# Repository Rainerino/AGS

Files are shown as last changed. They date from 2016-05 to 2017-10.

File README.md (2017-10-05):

## Project name: Air Guitar System(AGS)

Group memeber: 

Carmen Sing

John Kim

Yiyi Yan

Harry Li

Ringo Wong

## Introduction

The Air Guitar System (AGS) is designed to mimic the abilities of an electric guitar but playability of a simple button pushing device.  

Much of the design consideration has been geared towards stimulating accurate sound of electric guitar and creating easy to use interface in order to mitigate a learning curve.  

With these requirements in mind, our team created a fully functional instrument that can be played anytime, anywhere.  Our "guitar" do not require strings, large sound board or further tuning.  Aside from mimicking the ability of a regular guitar to stop music and vary volumes based on strumming patterns, many additional features have been included to improve upon a regular guitar such as one for all strumming distance, virtual button replacing the painful picking experiencec. 

## Motivation

Throughout history a common outlet for creativity is through music.  Research has shown that guitar is gaining traction by fast becoming the most popular instrument played due to its versatility, relatively lower cost (compared to pianos) and the rise of rock and pop music.  Our team aims to bring the freedom of creative expression to everyone while addressing some common complaints.  There have been similar projects in the past, however, our project aims to further improve the instrument by targeting problematic areas such as further reducing the cost of, and improving the portability and ease of composition.  We aim to accomplish two things: to simplify the instrument and to construct an intuitive design.  

## Prerequisities
* [Arduino](https://www.arduino.cc/en/Main/Software)
* [SFE_MMA8452Q library](https://learn.sparkfun.com/tutorials/mma8452q-accelerometer-breakout-hookup-guide/example-code)
* [toneAC library](https://playground.arduino.cc/Code/ToneAC)

## Modules 
Modules | Designation
--- | :---:
1 | Team_Resistor (main)
2 | Components
3 | Sound Calculation

### Components

This module is implemented in Project.header file. The functions of Components module included ultrasonic(), accGyro(), buttons() and pitch(). Each of the functions act as the driver for each sensors. 

### Sound Calculation

This module composes of two functions: playSound(), setPin() and the header file pitch.h, which has the wave defination od different notes to generate a song. The array chords in the Project header is a tester for the function. 

## Code Example

\#include "Project.h"
Project guitar; 
void setup() 
{
  guitar.setPin();
}
void loop() 
{
  guitar.playSound(); 
}

## References

See Final documentation.docx

## Contributors
Carmen Sing: csing00@langara.bc.ca

John Kim:hkim52@langara.bc.ca

Yiyi Yan: yyan10@langara.bc.ca

Harry Li: mli43@langara.bc.ca 

Ringo Wong: rwong22@langara.bc.ca

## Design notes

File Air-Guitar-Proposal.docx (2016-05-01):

Arduino Air Guitar

Description

The goal of this project is to create a guitar using the Arduino MEGA 2560 by replicating the both the sounds and playstyle of an actual guitar; without the strings and fret board. Using ultrasonic sensors, the distance between either hands will be measured to determine the fret and strings (buttons) to play the correct tone. On the other hand, an accelerometer with gyroscope will be used to determine whether the user is strumming or not. With the air guitar, the user will be able to simply strum in the air to play music.

Objectives

1. Create a functional air guitar with the Arduino MEGA 2560
2. Four strings playback as an acoustic guitar (and multiple instruments if time permits (e.g. acoustic/electric guitar, and ukulele))
3. Ability to strum naturally as you would on a regular guitar
4. Speaker playback with volume control and accurate sound
5. Recording MP3 files and retrieving musical data in both .mp3 format and in excel from the SD card

The air guitar is made original as we will have the following improvements:

1. MP3 shield instead of using buzzer speakers, auxiliary cable capability (better dedicated speakers)
2. The use of various tone libraries to mimic multiple string instruments, not just a guitar
3. The Guitar will not limited to half-fret increments
4. The guitar will have a more refined design
5. The Guitar will utilise an SD card to record play sessions that will allow the user to: retrieve (sample clips) as MP3 file and notes played in excel file format (for composition)
6. The Guitar will also have a switch to replay sessions – e.g. last played feature
7. The user will be able to stop the sound from the guitar by moving the right hand- holding the “stick”-towards their body, like a real guitar
8. An app will be made if we have more time (e.g. a game like Guitar Hero®)

Methods

To help us achieve a functional guitar we will refer to the online guide through intructables.com (4). As the guide is lacking in many aspects, further research has been done using other online resources such as Adafruit and Github. Thorough research has been completed to ensure each member understands the component’s abilities and limitations by using readily available datasheets from manufacturers and specifications as depicted by wholesalers.

Three main hardware parts will be used to create our guitar: the ultrasonic sensor (HC-SR04), accelerometer and gyroscope (MPU-6050 GY-521), and MP3 player shield (VS1053B). Together with the button switches that determine which strings are used, the ultrasonic sensor will be used to determine the distance from a reference point and therefore the fret played. The accelerometer will be used to determine when the instrument will be in use and activate the sound as needed. The z-axis will be used for the up/down motion and a negative x-axis will abruptly stop the music playback. As the instrument is played, the MP3 player shield is used to record the .mp3 file and notes in .xml (Excel®) and output the correct notes to the speaker connected through an auxiliary cable.

To achieve the objective of natural strumming on the air guitar, rigorous testing will be completed by our demonstrator, Carmen. The instrument will be tested for compliance to standards set by our team and adjusted accordingly.

Roles and duties have been assigned and agreed upon by all members. A timeline with set objectives have been created. Everyone on the team will be kept accountable for their respective parts. Communication is kept open at all times through Facebook Messenger group chat and regular team meetings have been scheduled to discuss the project. We will also consult our instructor and lab assistant if we need extra help.

Timeline

February 3rd 2016 to February 15th (week and week 2) | Preparation Period (First meeting Monday February 15th) 1. Initial documentation for preliminary process 2. Design modular codes for each component 3. Research and acquire all necessary components
February 16th to March 2nd (Week 3 and week 4) | Prototyping Period 1. Assemble all the components 2. Functional accelerometer, ultrasonic sensor and speakers to be completed
March 3rd to March 31st (Week 5 ,6 ,8 and 9) | Integration Period 1. Integrate all the components 2. Ensure the assembled prototype is functional 3. Test: play 3 songs, successfully
April 1st to April 11th (Week 10) | Further Tests and Improvements: 1. Complete documentation 2. Add additional sound library 3. If there is time, create an app.

Division of Work

Group Leader: Ringo Wong

Will ensure all members are following the timeline. He will be available for advising the rest of the members on each of their tasks. He will do all final checks and edits on documentation and coding to ensure a good standard of work. He will also be in charge of the coding for the accelerometer and testing it before putting all the components together. He will also help do soldering work on the hardware. He researched and compiled a list of components and then acquired these components.

Software Librarian: Yiyi (Albert) Yan

He will be in charge of the coding of the ultrasonic sensor and testing it. He will merge the coding of the accelerometer, mp3 shield and SD card and ultrasonic sensor. He also completed the preliminary research to research various methods to accomplish our project. He will be in charge of soldering work on the hardware.

System Test Manager: Hyunwoo (John) Kim

He will be in charge of coding and testing the MP3 shield. He will implement the read and write ability for the SD card so that we can utilise the last played feature and its retrieval. He will ensure that the final code is well documented with comments and make sure that the code is modular and easy to read. He will also be programing switches to toggle between various modes. He will also be responsible for coding the correct tone library for accurate sound replication.

Documentation Coordinator: Carmen Sing

She will record all meeting minutes. She will write the project proposal and draft the group presentation slides. She will do the diagrams (block, data flow etc.) and schematic sketches (5)(6)(7) required for project documentation. She will choose the song to play and also help with the testing for the air guitar prototype to ensure natural strumming and sound and she demo the guitar on the final day. She will provide visual aids in the proposal. She will assist with general coding.

Hardware Design Leader: Minggang(Harry) Li

He will help Carmen with project documentation, such as diagram (block, data flow etc.) and schematic .He will design the cylindrical container that the left hand holds and the rectangular container strapped to the right hand which will to contain the buttons. He will be in charge of wiring the final product. He will help john with the SD coding as well as the excel files logging of tones played.

Note: All members can edit any documents to provide suggestions and corrections. Any member of the group may also be asked in while the project is in progress to help another member if they are struggling with their task

Equipment

ITEMS | AMOUNT | Further Details
MP3 Player SHIELD- VS1053B to decipher midi codec and mp3 | X1 | Refer to (2)
ULTRASONIC SENSOR (HC-SR04) | X2 | Refer to (1)
ACCELEROMETER W/ GYROSCOPE (MPU6050 GY-521) | X1 | Refer to (3)
BUTTONS | X4
SPEAKER | X1 | Bluetooth auxiliary input speaker
AUXILIARY CABLE | X1
SD CARD | X1 | 2GB Kingston micro SD
SOLDER IRON | X1
MISC. (WIRES, RESISTORS, BREADBOARD, WIRE STRIPPER)

Sketches

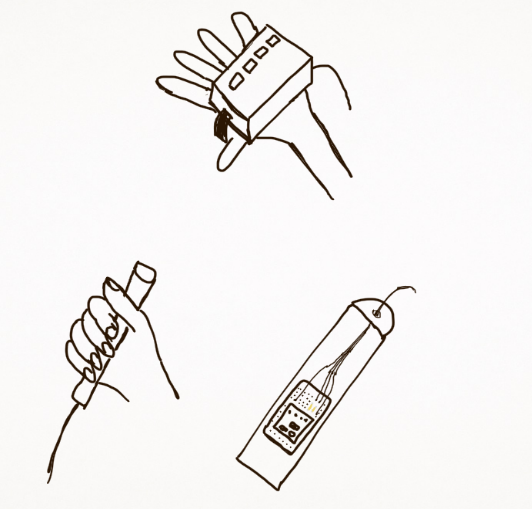
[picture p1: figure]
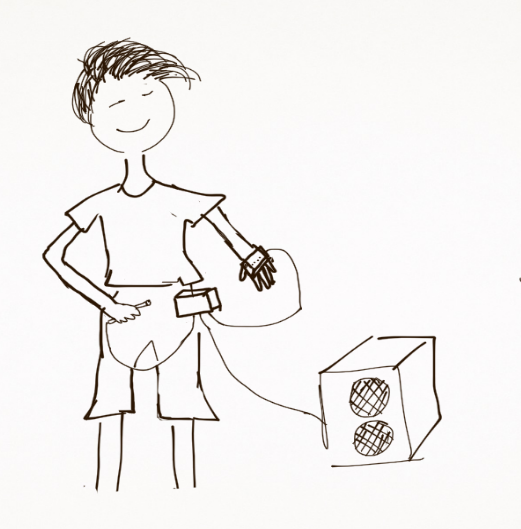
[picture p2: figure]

The whole set-up

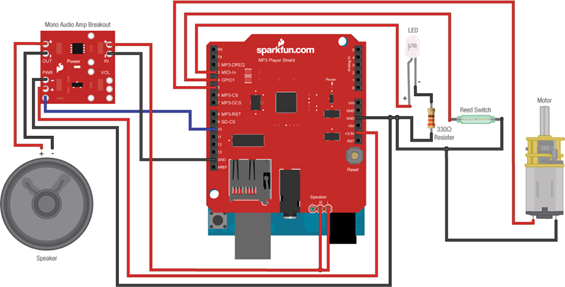
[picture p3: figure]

Mp3 player shield

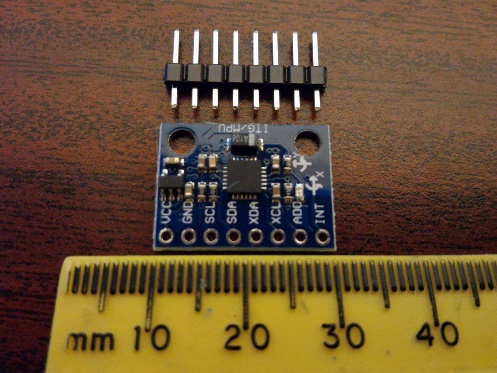
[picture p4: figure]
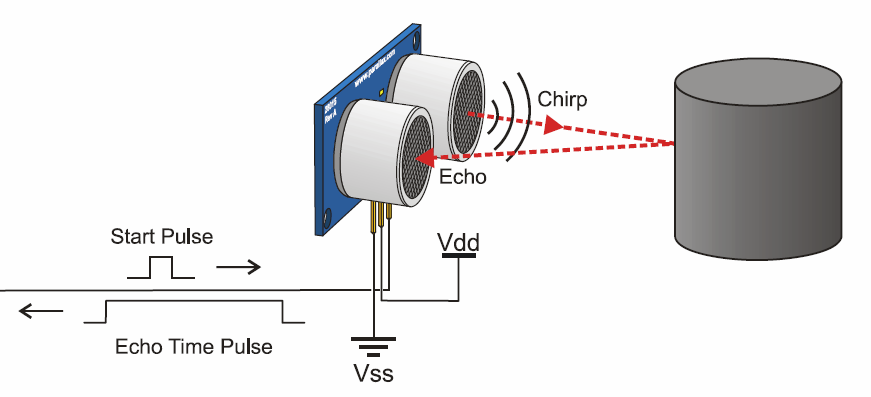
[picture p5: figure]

Accelerometer Ultrasonic Sensor

References

1. Ultrasonic Sensor

a) http://www.micropik.com/PDF/HCSR04.pdf

b) http://www.micropik.com/PDF/HCSR04.pdf

2. MP3 Shield
a) http://www.elechouse.com/elechouse/images/product/Arduino%20MP3%20Shield/Arduino%20MP3%20Shield%20User%20Guide.pdf
b) https://cdn.sparkfun.com/datasheets/Dev/Arduino/Shields/VS1053B.pdf
3. Accelerometer and Gyroscope MPU 6050 GY521

a) https://www.sparkfun.com/products/11028

b) http://playground.arduino.cc/uploads/Main/MPU6050-V1-SCH.jpg

4. http://www.instructables.com/id/How-to-build-an-Air-Guitar-with-Arduino-aka-the-A/

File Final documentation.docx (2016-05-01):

# Team Resistors: Air Guitar System

Carmen Sing, Hyun Woo (John) Kim, Yiyi Yan, Minggang (Harry) Li, Ringo Wong

Langara College

Engineering Transfer Program

100 W 49th Ave, Vancouver, BC V5Y 2Z6

csing00@langara.bc.ca hkim52@langara.bc.ca yyan10@langara.bc.ca mli43@langara.bc.ca rwong22@langara.bc.ca

# Abstract

Throughout history a common outlet for creativity is through music. Research has shown that guitar is gaining traction by fast becoming the most popular instrument played due to its versatility, relatively lower cost (compared to pianos) and the rise of rock and pop music. Our team aims to bring the freedom of creative expression to everyone while addressing some common complaints. There have been similar projects in the past, however, our project aims to further improve the instrument by targeting problematic areas such as further reducing the cost of, and improving the portability and ease of composition. We aim to accomplish two things: to simplify the instrument and to construct an intuitive design.

## Keywords

Accelerometer, Ultrasonic sensor, Arduino

# Introduction

The Air Guitar System (AGS) is designed to mimic the abilities of an electric guitar but playability of a simpler instrument, the bass guitar. Much of the design consideration has been geared towards accurate sound replications and ease of use in order to mitigate a learning curve. Our team will create a fully functional instrument that can be played anytime, anywhere. Our guitar will not require strings, large sound board or further tuning. Aside from mimicking the ability of a regular guitar to stop music and vary volumes based on strumming patterns, many additional features have been included to improve upon a regular guitar.

The AGS is designed so that the user can recreate the experience of a real guitar without the inconvenience of size, weight and cost. Select volunteers were able to intuitively play the instrument without prior encounter with the instrument. On the left hand, a glove is used to activate the buttons and cover the photo-resistors to determine the chord being played. In additional an ultrasonic sensor, measuring the distance between either hands of the player can accurately determine the chord and fret used. On the right, an accelerometer to replicate the strumming and abilities of an electric guitar.

# Similar Project

There exists a similar project, the Airduino Guitar⁶ based in Sweden. Graduate students completed a similar prototype for their Master program. Their project uses a glove with several buttons that represent half tones and a stick containing an accelerometer for strumming used simultaneously with an ultrasonic sensor. Due to the nature of half-frets, they had to customize the frequencies to correspond to their intended tones. A list of arrays were created that the program will run through every cycle and utilize a number of random distorted noises to imitate an actual guitar.

# Technical Specifications

This project was constructed with the knowledge and concepts obtained from CPSC 1490: Applications of Microcontrollers and CPSC 1155 Introduction to C++ courses as well as completing extensive research on the various aspects specific to the ACS project .

In terms of circuitry, all components are connected to the central processing unit: the Arduino MEGA 2560¹ which is a small programmable computer which is capable of single threaded processing. It comprises of a memory processor and input and output devices. A microcontroller is ideal for the air guitar project as it is affordable, flexible and easily programmable using C++ language.

The left hand consists of a glove tailored to cover the photo-resistors effectively. The photo-resistors act as buttons to determine which chord is being played. This is achieved by measuring the lux from the raw data from the photo-resistor. Complete darkness created by the glove, which covers the photo-resistor will activate the corresponding chord.

There are two main components of this project: the ultrasonic sensor, accelerometer. The ultrasonic sensor provides a range of 2cm - 400cm of non-contact measurement. The ranging accuracy of the ultrasonic sensor is approximately 3mm. The speaker modules include the ultrasonic transmitters, receiver and control circuit². The ultrasonic sensor is made more accurate by unsoldering the transmitter and receiver to place the two sensors directly opposite of each other and recalibrating it to measure the distance between the transmitter and receiver rather than a reflected sound wave off a surface. The ultrasonic sensor was disassembled by unsoldering the connections and separating the two sensors. The side of the ultrasonic which emits the sound wave is called the trigger and the side that receives the sound wave is called the echo. We also included four LEDs to help the user learn where the different fret distances are in the air. By using the distance measured we can determine the chord played, various octaves were determined by measuring distances, which were calibrated manually with respect to a full-sized adult electric guitar.

The user’s right hand will contain the accelerometer³ and the echo (receiving) part of the accelerometer. The pins of the accelerometer were carefully soldered to create the sturdy connection required between chip and the rest of the circuit. The accelerometer uses micro crystals that go under stress when vibrations occur due to movement, from this stress a voltage is returned to determine the acceleration. To detect the strum, the raw data was calibrated to see if the difference in the raw data between the time that movement was detected and the end of the movement is greater that a certain value in order to be declared a strum. To stop the sound played, the pitch becomes zero so that there is no sound output. This happens when the difference in the raw data reading is less than the required range for it to be declared a strum.

Finally there is two ways to assign the notes of guitar to be played, one way is to use the “toneMelody” example in the Arduino program and the other way is to use the tone library provided in the Airduino project⁶ which contains a playable library with individual tones. The sound will also fade to become more realistic.

A speaker will be connected to the Arduino MEGA 2560 to allow it to have a better sound quality and higher volumes.

All the hardware of the project was encased in a custom designed containers structured and planned though AutoCAD. The material of the hardware was chosen to be hard cardboard with a layer of foam in between as it is more affordable, rigid and protective.

# Artefact Display

The entirety of the project and its documentations can be found online. It can be accessed anywhere with access to the internet. The AGS website will contain progress reports, documented photos as well as open source resources available.

# Testing

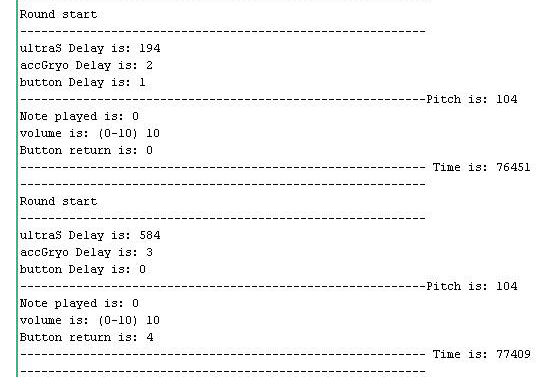
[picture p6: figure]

In order to test and debug the prototype we use the above responses on the serial monitor:

The first thing the microcontroller reads is the ultrasonic sensor which returns a distance in centimetres. It then chooses a distance note and index is. There are 4 buttons which are labelled 0 to 4. The pitch is measured in hertz and time is how it runs in milliseconds. To check it runs successfully it returns the word “GOOD!!!!”

To remove delays, serial monitor prints were commented out of the program and interrupt functions were also removed.

# Future Plans

Engineering the prototype, certain cutbacks were made after careful consideration. Due to constraints from time, cost, and weighing the benefits, we have decided to postpone several features. First, the capability to play multiple string instruments, such as the ukulele or violin, has been removed temporarily due to time constraints. While not difficult to implement after the first tone library, the time required to make multiple instrument profiles was found to be exceed the time allotted.

In additional, future iterations of the project will include wireless capabilities. To be truly be portable guitar, the ability to play without cables is a must. Be that as it may, factoring in the total cost and our budget, the improvements are not a viable option at this time. The more expensive model will require a WI-FI shield, and a Bluetooth shield.

Lastly, there are inconveniences associated with a wireless setup: a portable battery will be required to power the Arduino Microcontroller wirelessly which will add to the overall weight and require users to always have a charged battery cell on hand.

The AGS may be able to send messages via serial communication to the webpage and process all the raw data retrieved from the sensors.

The prototype may also eventually be adapted to be a game similar to Guitar Hero® but with the versatility to become any instrument and not just a guitar.

The MP3 Player Shield⁴ could also be used to output the appropriate tone, and record notes played into both .xml and .wav files. The MP3 Player Shield can play many formats including MP3, WMA, WAV, AAC, MIDI, Ogg, and Vorbis. The Music Shield is an audio encoder/decoder compatible with Arduino Mega. It is based on the VS1053B chip, which enable it to play sound files from SD card and do short-time recording as well. You can also use it to play MIDI notes by slightly changing its hardware installations. Due to the SPI communication mode, it keeps a minimum number of IO port that facilitates users’ own developments of this device. Another possible method of creating realistic sounds is using the One-Bit DAC theory.

# Problems

We originally intended to use the MP3 player shield to play background music and record songs; however, it was the greatest problem with the prototype was the MP3 Player Shield as we struggled to find a working library. The one provided by Geeetech⁴ has many bugs which renders the library unusable. Another issue is the fact that the MP3 Music Shield is only able to play one sound clip at a time and must finish the entire clip before beginning the next one. Due to the time constraints and difficulty we had to remove the MP3 Player Shield from our project.

# Results

The ultrasonic sensor successfully detects the change in distance and applies the change in sound accordingly. The accelerometer can also detect strumming and stop sound when the strumming stops. The sound outputted by the AGS is similar to an electric guitar.

# Conclusion

Through this project we have learnt many things. For example, how to implement the ultrasonic sensor and accelerometer and understand its capabilities and limitations. Equipped with a greater understanding of the individual parts allowed us to use the ultrasonic in a different way from how they were meant to be used and customize it to better suit our needs. In addition, through extensive research, we were able

to improve the sound quality beyond the half-frets achieved by previous iterations of the project and have the foresight to create better buttons with photo-resistors. Although the use of the MP3 Music Player resulted in it being scrapped from the project, it offered a very rewarding learning experience. With time and a functional library, it is possible to create a very complex sound synthesizer with the music maker shield. Future iterations of the AGS may include the MP3 music player to break beyond the limitations of the pitch/tone libraries and create sounds from any instruments.

Moreover, we also learnt useful hardware skills in this project such as efficient cable management, good soldering practices, modular coding, prototyping, effective communication and teamwork to accomplish the tasks required for a project of this nature.

# Acknowledgements

Our team would like to thank Todd for his support both financially and as a mentor. We would also like to take the opportunity to thank Richard, Csilla, Terry, Henry for taking the time to be there for our presentation. Lastly, the biggest thanks for Pooya for being an awesome instructor, and providing us with relevant resources to help us with the project.

# References

1. Arduino MEGA 2560
i. Technical specifications and documentation: https://www.arduino.cc/en/Main/arduinoBoardMega2560
2. Ultrasonic Sensor HC-SR04
i. Technical specifications: http://www.micropik.com/PDF/HCSR04.pdf
3. Sparkfun MMA8452Q accelerometer
i. Schematic: https://cdn.sparkfun.com/datasheets/Sensors/Accelerometers/SparkFun_MMA8452Q-Breakout.pdf
ii. Datasheet: https://cdn.sparkfun.com/datasheets/Sensors/Accelerometers/MMA8452Q-rev8.1.pdf
iii. Library: https://github.com/sparkfun/SparkFun_MMA8452Q_Arduino_Library/tree/V_1.1.0
4. MP3 Music Shield (VS1053)
i. Documentation, technical specifications and schematic http://www.geeetech.com/wiki/index.php/Arduino_Music_Shield_V2.0
5. Advanced sound synthesis (One-Bit DAC theory): http://makezine.com/projects/make-35/advanced-arduino-sound-synthesis/
6. Initial Guitar Concept Reference: http://www.instructables.com/id/How-to-build-an-Air-Guitar-with-Arduino-aka-the-A/
7. Final Proposal Reference: http://www.sfu.ca/~arlalau/320_research_paper.pdf

# Appendices

Auto Cad Designs:

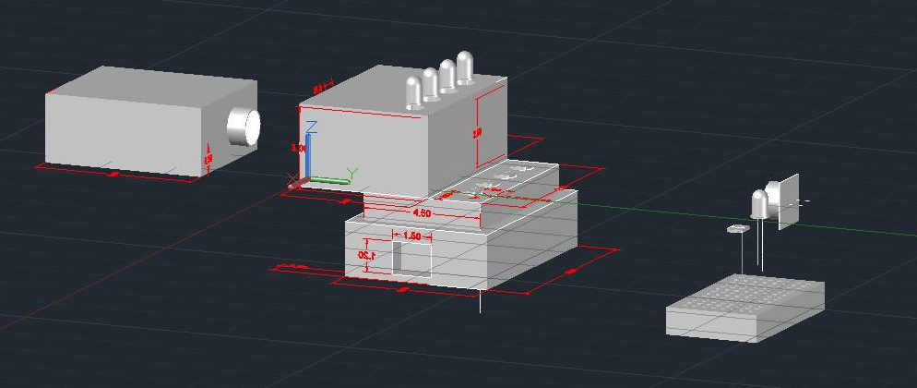
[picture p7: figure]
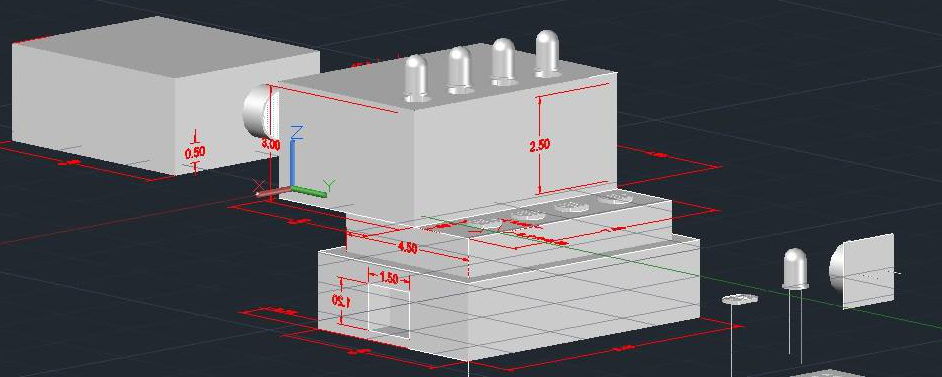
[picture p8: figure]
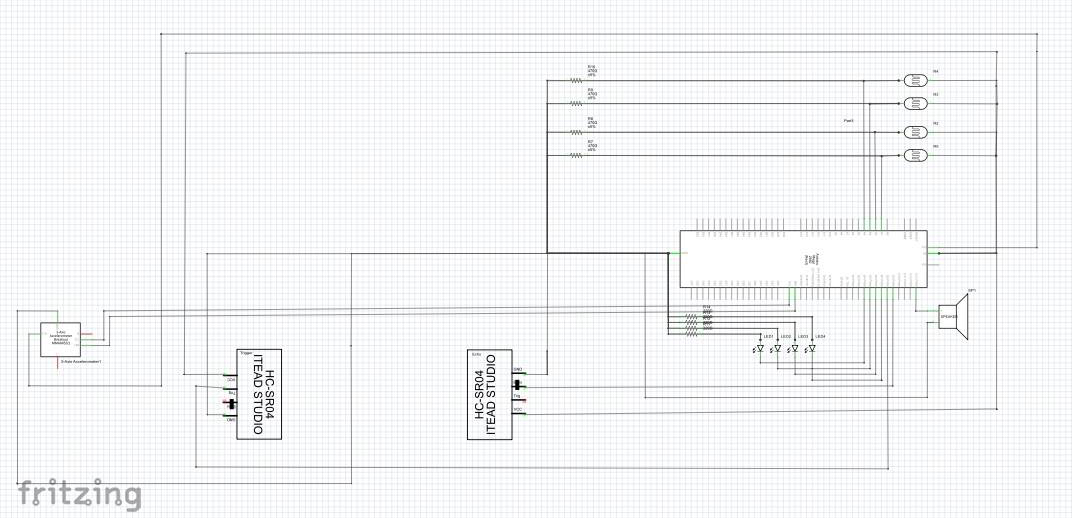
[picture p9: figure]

Schematic Design

Block Diagram

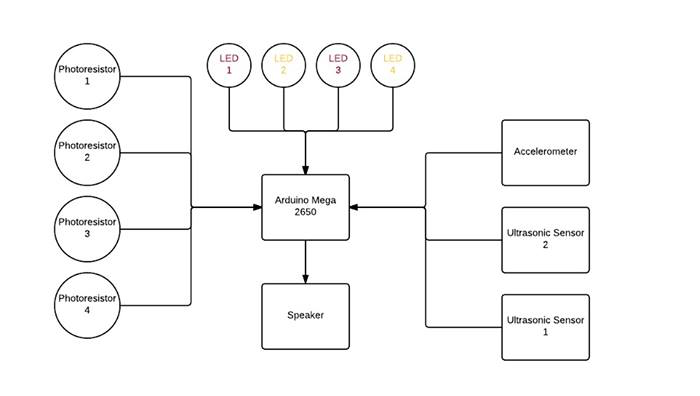
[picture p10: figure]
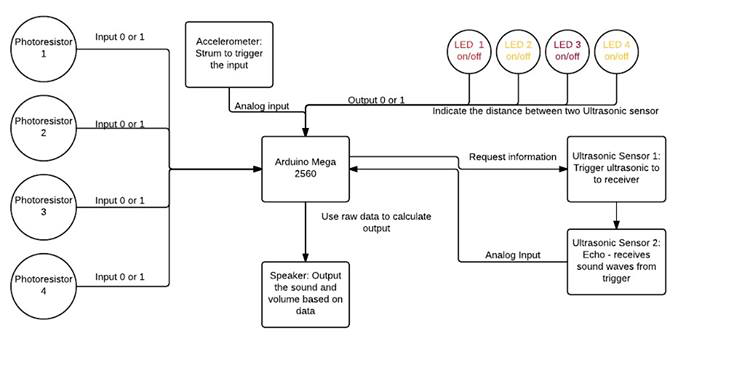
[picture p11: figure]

Data Flow Diagram

State Diagram

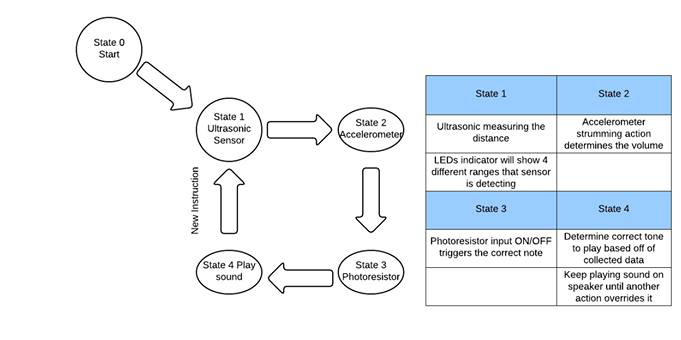
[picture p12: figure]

Code:

/*

* Program name : Team_Resistor

* Project name : Arduino Air Guitar System

* Purpose : outputs sound of guitar notes which are determined by several sensors: ultrasonic sensor, accelerometer, and photoresistors

* Author: Ringo Wong, John Kim, Carmen Sing, Harry Li, Yiyi Yan

* Date: 21 Mar 2016 to 18 April 2016

* Course: CPSC 1490 Langara College

*

* Note : Serial Output functions ( for monitoring ) are commented out

*/

#include "Project.h"

Project guitar; // initialize class

void setup()

{

guitar.setPin();

}

void loop()

{

guitar.playSound();

}

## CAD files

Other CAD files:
AGS/Original/airGuitar_03_recover(final).dwg

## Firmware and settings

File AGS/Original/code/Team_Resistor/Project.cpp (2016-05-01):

  
 #include "Project.h"

 const int chords[4][5] = { { NOTE_GS2, NOTE_G2, NOTE_FS2, NOTE_F2, NOTE_E2 },   // frequencies of 4 strings and 5 frets of a guitar ( bass guitar ) 
                          { NOTE_CS3, NOTE_C3, NOTE_B2, NOTE_AS2, NOTE_A2 },     // chords[string#][fret#] 
                          { NOTE_FS3, NOTE_F3, NOTE_E3, NOTE_DS3, NOTE_D3 },
                          { NOTE_B3, NOTE_AS3, NOTE_A3, NOTE_GS3, NOTE_G3 } };
                      
 const int soundDecay[] = { 10, 9, 8, 7, 6, 4, 2, 0 }; // set of volumes for sound fading sequecence
 
  Project::Project()
  {
    //default pitch
    PITCH = 39;
    index = 0;
  }
  
  /* Ultrasonic()
   * The following function returns the corresponding NOTE# based on the distance reading from the ultrasonic sensor
   * NOTE: the NOTE return can be bigger than 3. The filter function is pitch
   * 
   * @parameter(void)
   * @return(int) (NOTE_number) - the NOTE number from user
  */
  int Project::ultrasonic()
  {
    
   //the maximum value of raw data from ultrasonic
   int temp = 16000;
   
   // collect data three times, and use the smallest value to improve accuracy 
   // single data reading takes approximately 60ms average
   
  for(int i = 0 ; i < 3 ; i++)
  {
    // emit ultrasonic sound wave  (trigger)
    digitalWrite(trigPin, LOW); 
    delayMicroseconds(2); 
    digitalWrite(trigPin, HIGH);
    delayMicroseconds(5); 
    digitalWrite(trigPin, LOW);

    // time took to recieve the emitted ultrasonic (reciever)
    duration = pulseIn(echoPin, HIGH, 3000);
    
    if( duration != 0)
    {
      //if raw data ( duration ) is not zero ( out of bound or error ), store the minimum value
      temp = min(temp, duration);
    }
    else
    {
      //if raw data is zero ( out of bound or error ) read data again
      i--;
    }
  }
  
    //convert raw data to the distance for easier calculation ( arbitrary unit )
    distance = temp / 20;
    
    //map the distance into 5 regions ( 0 to 4 ), which will be considered as NOTE#
    fret_number = map( distance, MinDistance, MaxDistance, 0, NoteSize - 1 );
    
    /* 
     * The following function controls the LED's based on the value of distance 
     * the LED's will light up to corresponding regions and help user visulalize which NOTE is being played
     * 
     */
    switch (fret_number)
    {
      case 0:  // open string 
      digitalWrite(LED1, HIGH);
      digitalWrite(LED2, LOW);
      digitalWrite(LED3, LOW);
      digitalWrite(LED4, LOW);
      break;
      
      case 1:  // first NOTE 
      digitalWrite(LED1, LOW);
      digitalWrite(LED2, HIGH);
      digitalWrite(LED3, LOW);
      digitalWrite(LED4, LOW);
      break;
      
      case 2:  //second NOTE 
      digitalWrite(LED1, LOW);
      digitalWrite(LED2, LOW);
      digitalWrite(LED3, HIGH);
      digitalWrite(LED4, LOW);
      break;
      
      case 3:  //third NOTE 
      digitalWrite(LED1, LOW);
      digitalWrite(LED2, LOW);
      digitalWrite(LED3, LOW);
      digitalWrite(LED4, HIGH);
      break;
      
      case 4:  //fourth NOTE
      digitalWrite(LED1, HIGH);
      digitalWrite(LED2, HIGH);
      digitalWrite(LED3, HIGH);
      digitalWrite(LED4, HIGH);
      break;
      
      default: 
      break;
    }
    return fret_number;
}

/*
 * accGyro()
 * The following function will return a volume between 0 and 10 based on the acceleration of the accelerometer 
 * Default volume is 2 
 * 
 * @parameter(void)
 * @return(double) (temp) - movement of the accelerometer ( strumming )
 */
  double Project::accGyro()
  {
    if ( accel.available() ) //if accelerometer is available 
    {
        accel.read(); // take raw reading
        currAcc = accel.cx + 4; // x-axis coordinate value is stored 
        double temp = abs(currAcc - lastAcc); // stores the difference in coordinates 
        lastAcc = currAcc; // stores to compare it with the next reading
        return temp;
      }
  }
  
  /*
   * The following function deteremines the string# from photoresistor reading value
   * returns string# of 0, 1, 2, 3 
   * 
   * @parameter(void)
   * @return(int) - the string number user inputs
   */
  int Project::buttons()
  {
    //read photoresistor, and if covered with finger, return true ( 1 )
    button_1 = ( analogRead(button1Pin) < lightBrightness ) ? 1 : 0 ; 
    button_2 = ( analogRead(button2Pin) < lightBrightness ) ? 1 : 0 ; 
    button_3 = ( analogRead(button3Pin) < lightBrightness ) ? 1 : 0 ; 
    button_4 = ( analogRead(button4Pin) < lightBrightness ) ? 1 : 0 ; 
 
    if( ( button_1 == 1 && button_2 == 0 && button_3 == 0 && button_4 == 0 ) ) // button_1 represents first string 
    {
      return 0;
    }
    else if( button_1 == 0 && button_2 == 1 && button_3 == 0 && button_4 == 0 ) // button_2 represents second string 
    {
      return 1;
    }
    else if( button_1 == 0 && button_2 == 0 && button_3 == 1 && button_4 == 0 ) // button_3 represents third string 
    {
      return 2;
    }
    else if( button_1 == 0 && button_2 == 0 && button_3 == 0 && button_4 == 1 ) // button_4 represents fourth string 
    {
      return 3;
    }
    else
    {
      return 4; //error vaule
    }
}

    /* playSound()
     * chooses the corresponding frequency and outputs to the speaker
     * 
     * @parameter(void)
     * @return(void)
     */
  void Project::playSound()
  {
      fret = ultrasonic(); // the fret number 
      double temp = accGyro();
      string = buttons(); // the string number
      
      pitch(fret, string); // call function pitch()
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
